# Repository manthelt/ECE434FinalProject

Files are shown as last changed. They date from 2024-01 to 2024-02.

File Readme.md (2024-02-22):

# ECE434 Sound Project
 Larissa Krakora, Ash Collins, Logan Manthey

<!-- markdown-toc start - Don't edit this section. Run M-x markdown-toc-refresh-toc -->
**Table of Contents**

- [ECE434 Sound Project](#ece434-sound-project)
    - [Executive Summary](#executive-summary)
    - [Packaging](#packaging)
    - [Installation Instructions](#installation-instructions)
    - [User Instructions](#user-instructions)
    - [Highlights](#highlights)
        - [Video](#video)
    - [Theory of Operation](#theory-of-operation)
        - [Hardware](#hardware)
            - [BOM](#bom)
            - [Keyboard Section](#keyboard-section)
                - [Schematic and PCB](#schematic-and-pcb)
                - [Resistor List for Note Values](#resistor-list-for-note-values)
            - [Pot Section](#pot-section)
        - [Software](#software)
            - [Reading in the values](#reading-in-the-values)
            - [Creating Sound](#creating-sound)
            - [Storing Recorded Sound](#storing-recorded-sound)
            - [Changing Octaves](#changing-octaves)
            - [Switching Songs](#switching-songs)
    - [Work Breakdown](#work-breakdown)
    - [Future Work](#future-work)
    - [Conclusions](#conclusions)

<!-- markdown-toc end -->

## Executive Summary

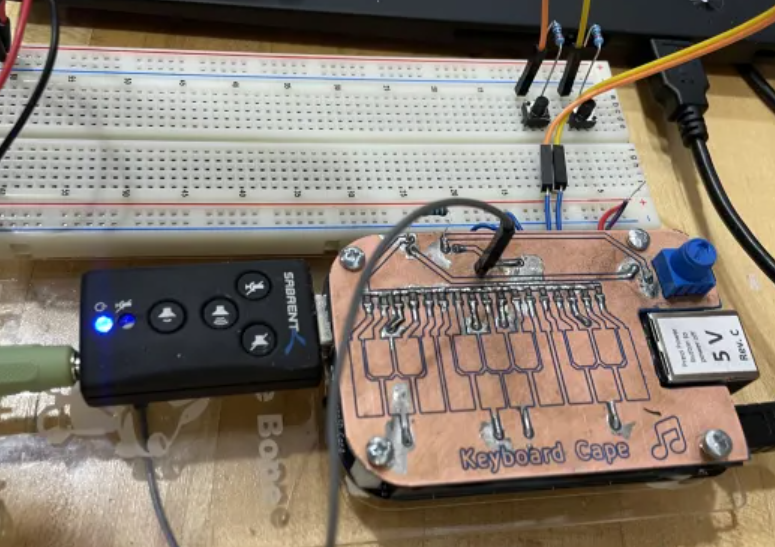
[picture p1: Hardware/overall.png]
|  | 
|:--:| 
| *Project Overview* |

This project is centered around making a digital synth using a custom designed keyboard cape. The inspiration for this project came from the Stylophone, an analog synth which used a stylus keyboard. Our project currently has capability to play songs, navigate songs, take and play user input, record and play back user input, and has two octaves for that "manual mode". We also have a simple UI via Flask for the controls, and the display of the title of the current song. We wanted to add audio visualisation on an LCD, but we were barely even able to get anything to display on the LCD. We gave that up as we sunk too many hours into it and would rather add new features. Our project has many different capabilities related to sound.

## Packaging
- Most of our product is standard wires, pots, switch buttons, etc. except for our custom "Keyboard Cape"
- Our cape acts as a voltage divider, allowing us to read in analog values of voltage to differentiate between notes

Hackster IO Link: https://www.hackster.io/larissa3/sound-project-77327a

ELinux Page Link: https://elinux.org/ECE434_Project_-_Sound_Project

## Installation Instructions
- Read-only GitHub: https://github.com/manthelt/ECE434FinalProject

1. Clone the repo
2. Run sudo ./install.sh
3. Run sudo ./setup.sh
4. Move .asoundrc to your home directory
5. Use aplay -l to find out which card your USB Audio device is setup as
6. Change 
    pcm "hw:0,0" -> pcm "hw:[card #],0" 
    and
    card 0 -> card [card #]
    in ~/.asoundrc

- Custom PCB schematic in 'Schematic and PCB'
- USB Surround Sound Adapter: https://sabrent.com/products/usb-sbcv

## User Instructions
1. Run ./recordServerNew.py
2. Visit https://localhost:8081

## Highlights
- Play a variety of songs
- Backward, pause/play, and skip functionalities
- "Manual mode" that allows the user to play their own sequence of notes
- Record a sequence of notes and play them back

### Video
Here is a video that shows our project in operation.

[Sound Project Demo Video](https://youtu.be/Gq4ZqvmgP8Y?si=p0Maj8yswmgwlebh)

## Theory of Operation
- Input from buttons > navigate through songs > display via Flask
- Input from cape while in manual mode > play various notes
- Manual mode is navigated to the same way other songs are > input only taken in during manual mode > other songs do not play during manual mode

### Hardware
This section decribes the hardware portion of the project and which parts and designs were used.

#### BOM
    - 17 1206 Resistor of Varying Sizes
      -  [Resistor List for Note Values](#resistor-list-for-note-values)
    - 1 Potenimeter
    - 2 2 Pin Male Connectors
    - 1 1 Pin Male Connector 
*Note for the connectors I used large ones that I cut down to size*

#### Keyboard Section
This section decribes the keyboard section of the hardware and it's theory of operation 

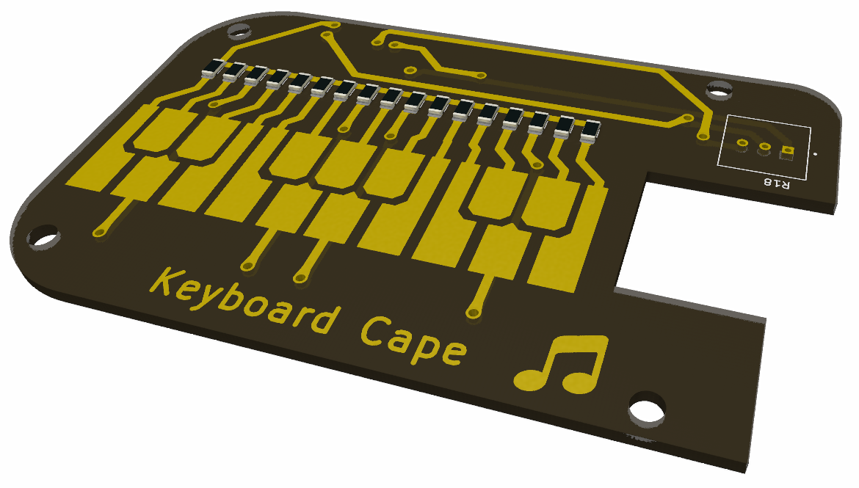
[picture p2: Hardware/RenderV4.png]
|  | 
|:--:| 
| *Beagle Bone Keyboard Cape Render* |

In short this keyboard acts as a form of potentiometer where connecting the 1.8 volt line to the different nets allows a different value to be read by the analog input as there is a different resistor connected to each one of the note nets.

##### Schematic and PCB
The keyboard cape was designed using KiCAD EDA software. KiCAD is an open source easy to use EDA software that allowed us to quickly design and then print out a PCB prototype on campus using the CNC mill. If we were going to redesign this for real manufacture we would add more headers to make it more stable. We would also add a spot for a pull down resistor to the board itself.

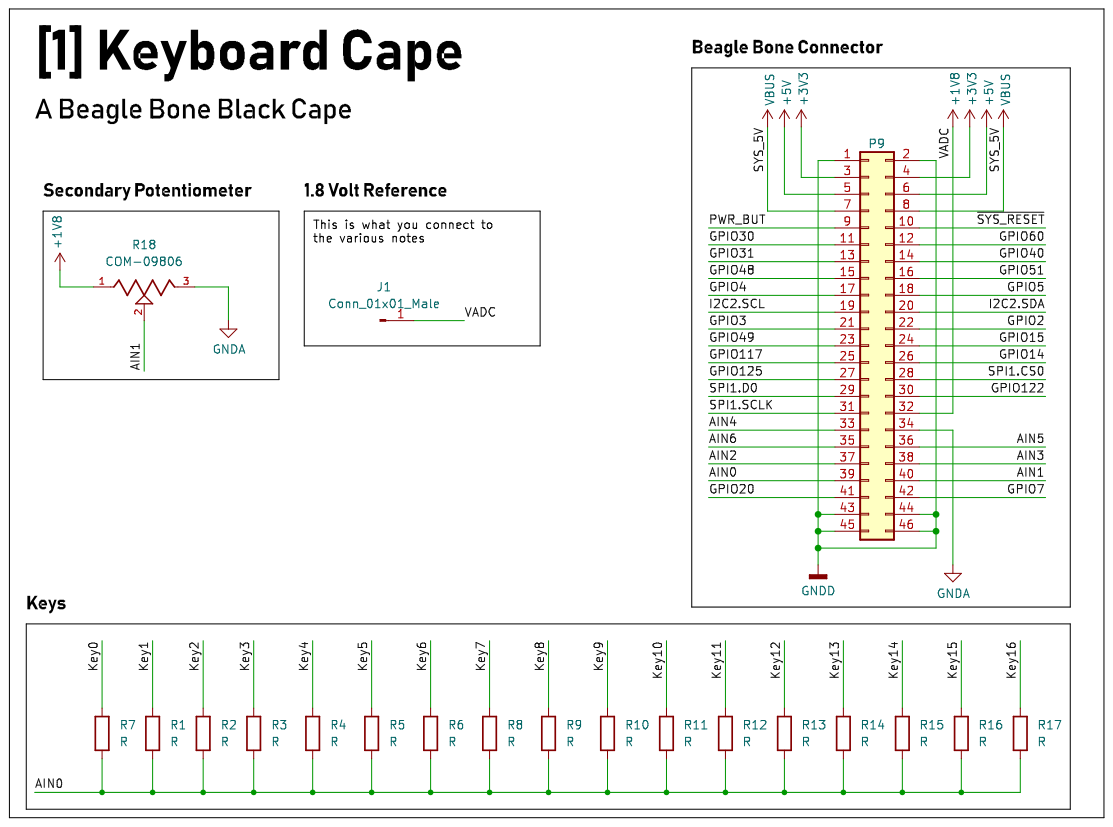
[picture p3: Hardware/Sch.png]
|  | 
|:--:| 
| *Beagle Bone Keyboard Cape Schematic View* |

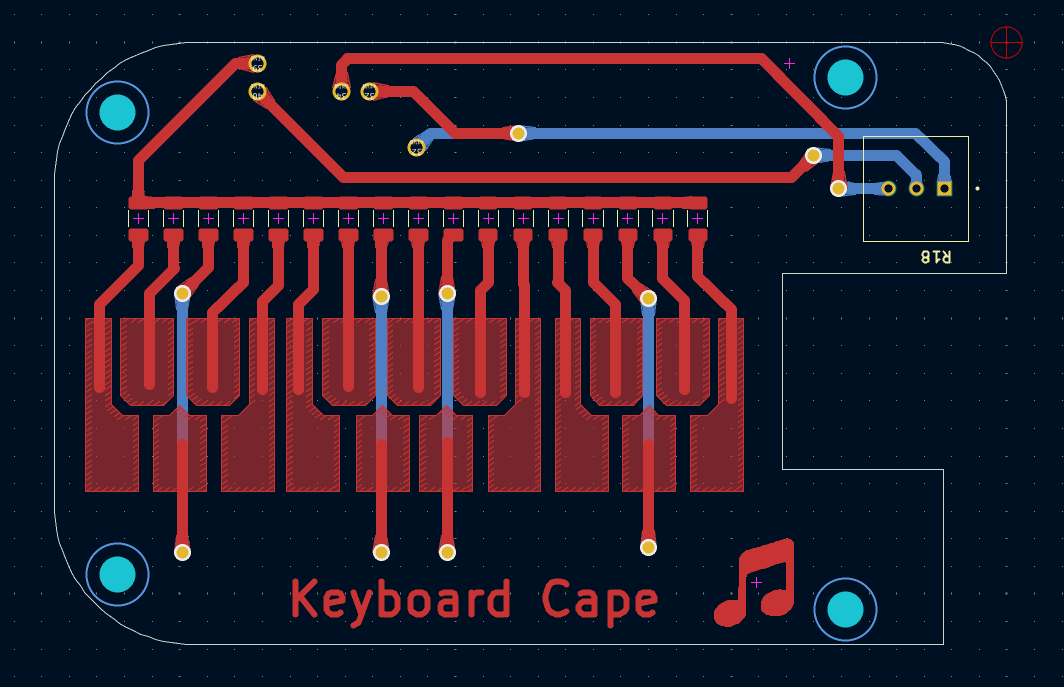
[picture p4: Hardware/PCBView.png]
|  | 
|:--:| 
| *Beagle Bone Keyboard Cape PCB View* |

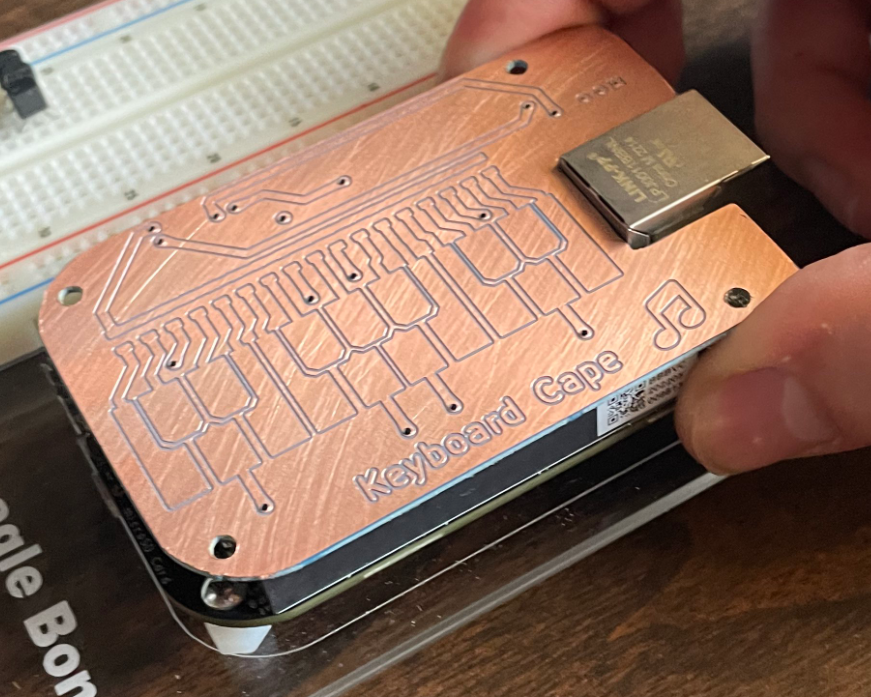
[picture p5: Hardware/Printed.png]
|  | 
|:--:| 
| *Beagle Bone Keyboard Cape Inital CNC Print* |

##### Resistor List for Note Values
These values were chosen to allow for a somewhat even distrubtion of values which will translate to a even distrubtion of values. We then added a pull down resistor to allow for a even larger distributing of notes. 

```
Note  Ohm
0     47000
1     33000
2     22000
3     15000
4     10000
5     6800
6     4700
7     3300
8     2200
9     1500
10    1000
11    680
12    470
13    330
14    220
15    150
16    100
17    0
```

#### Pot Section
In addition to the keyboard acting as a potentiometer there is also a normal potentiometer that can act as a volume control or however you would like to program it. That potentiometer is located here.

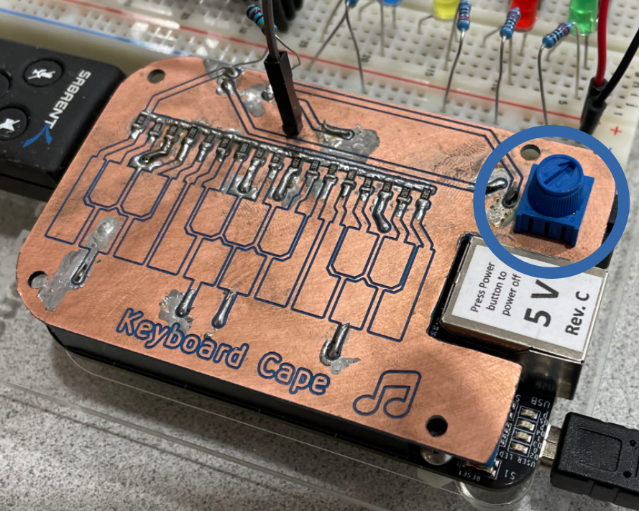
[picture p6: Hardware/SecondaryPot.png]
|  | 
|:--:| 
| *Beagle Bone Keyboard Cape Inital Print* |

### Software

#### Reading in the values
- Analog input via /sys/bus/iio
- Button input via gpio

#### Creating Sound
- While in manual mode, user hits the keys with connected wire
- Software reads in analog voltage input via /sys/bus/iio
- That analog voltage value corresponds to a frequency that is then played

#### Storing Recorded Sound
- User hits keys
- Notes are read in via /sys/bus/iio
- Durations are determined based on the time the user started playing the note and when they stopped

#### Changing Octaves
- Take in input from potentiometer
- Use that value as a boolean to determine offset for array index of frequencies

#### Switching Songs
- Buttons on Flask navigate to new page to control navigation through songs

## Work Breakdown

- PCB Design and Solder
  Logan

- Sound Generation and USB Audio
  Logan, Ash, Larissa

- LCD Visualization (not working - dropped)
  Ash, Larissa

- Flask
  Ash, Larissa

- Documentation
  Logan, Ash, Larissa

## Future Work
Future Additions
       - More features on the Flask App
       - More Synth Options and possbile Digital Signal Processing
         - Possible Second Pot Features
           - Pitch Bend
           - Wave Adjustment (Example: Sin Wave to Sawtooth to Square)
        - Being able to play over background songs and beats
          - This would let you solo with the keyboard over tunes like free bird
        - Adding a loop for recording playback would be able to allow for more intense soloing
        - LCD Screen
          - We attempted to get the LCD screen to work with the bone but this proved to be very
            difficult especially with a UI if we had LCD working with it we could make it into a
            smaller self contained package
        - Hardware
          - Adding buttons to the cape
          - Making the cape more stable on the bone
          - Printing the PCB at a PCB House

## Conclusions

Overall our group thinks our project was a success. Our approach of making something simple and
adding features to it proved to be very useful and allowed us to pivot as needed. This also
allowed us to always have something to demo at every stage of our project. We also thought
the interactive nature of the project made this a really fun project to demo.

Above in future work shows a few different features that we would like to add to the project.

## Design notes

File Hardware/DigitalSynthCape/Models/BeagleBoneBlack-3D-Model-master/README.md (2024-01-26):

BeagleBone Black 3D Model
=========================
 
SolidWorks 3D model of the BeagleBone Black

Contains the following:
- SolidWorks, IGES, STEP, STL files
- 3D PDF (open in Adobe Reader)

### To download, click "Download ZIP" to the right   ==>

Made available by Logic Supply based on information from BeagleBoard.org

Visit Logic Supply to buy the BeagleBone Black and accessories at http://www.logicsupply.com/products/bb_bblk_000

Follow us on Google+ for updates and more information: https://plus.google.com/u/0/b/103613886667848850929/

Designed by Rodney Hill and Hans Brakeley for Logic Supply.

Creative Commons Attribution 3.0 Unported License. To view a copy of this license,
visit http://creativecommons.org/licenses/by/3.0/. All text above must be included in any redistribution.

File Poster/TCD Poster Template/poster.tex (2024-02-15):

% unofficial poster template for Trinity College Dublin
% which is a fork of the unofficial University of Texas at Arlington Math Poster template:
% which is a fork of the unofficial University of Lethbridge Poster template: https://www.overleaf.com/latex/templates/university-of-lethbridge-unofficial-poster-template/nddfzgvqvfwf
% which is a fork of unofficial University of Alberta Poster template: 
% which is a fork of Yale template: https://www.overleaf.com/latex/templates/yale-poster-template/rjpgqfgvsjcv
% which is a fork of the UMich template https://www.overleaf.com/latex/templates/university-of-michigan-umich-poster-template/xpnqzzxwbjzc
% which is fork of the MSU template https://www.overleaf.com/latex/templates/an-unofficial-poster-template-for-michigan-state-university/wnymbgpxnnwd
% which is a fork of https://www.overleaf.com/latex/templates/an-unofficial-poster-template-for-new-york-university/krgqtqmzdqhg
% which is a fork of https://github.com/anishathalye/gemini
% also refer to https://github.com/k4rtik/uchicago-poster

\documentclass[final]{beamer}

% ====================
% Packages
% ====================

\usepackage[T1]{fontenc}
\usepackage[utf8]{luainputenc}
\usepackage{lmodern}
\usepackage[size=custom, width=122,height=91, scale=1.2]{beamerposter}
\usetheme{gemini}
\usecolortheme{msu}
\usepackage{graphicx}
\usepackage{booktabs}
\usepackage{tikz}
\usepackage{pgfplots}
\pgfplotsset{compat=1.14}
\usepackage{anyfontsize}

% ====================
% Lengths
% ====================

% If you have N columns, choose \sepwidth and \colwidth such that
% (N+1)*\sepwidth + N*\colwidth = \paperwidth
\newlength{\sepwidth}
\newlength{\colwidth}
\setlength{\sepwidth}{0.025\paperwidth}
\setlength{\colwidth}{0.3\paperwidth}

\newcommand{\separatorcolumn}{\begin{column}{\sepwidth}\end{column}}

% ====================
% Title
% ====================

\title{Some fancy title: followed by some more text}

\author{Your Name}
% add following line if you have co-author(s)
% Coauthor One$^{2}$, Coauthor Two$^{3}$

\institute[shortinst]{\textbf{Trinity College Dublin}, The University of Dublin}

% ====================
% Footer (optional)
% ====================

\footercontent{Mathposium \hfill
  \href{mailto:youremail@tcd.ie}{youremail@tcd.ie}}
% (can be left out to remove footer)

% ====================
% Logo
% ====================

% use this to include logos on the left and/or right side of the header:
% Left: institution
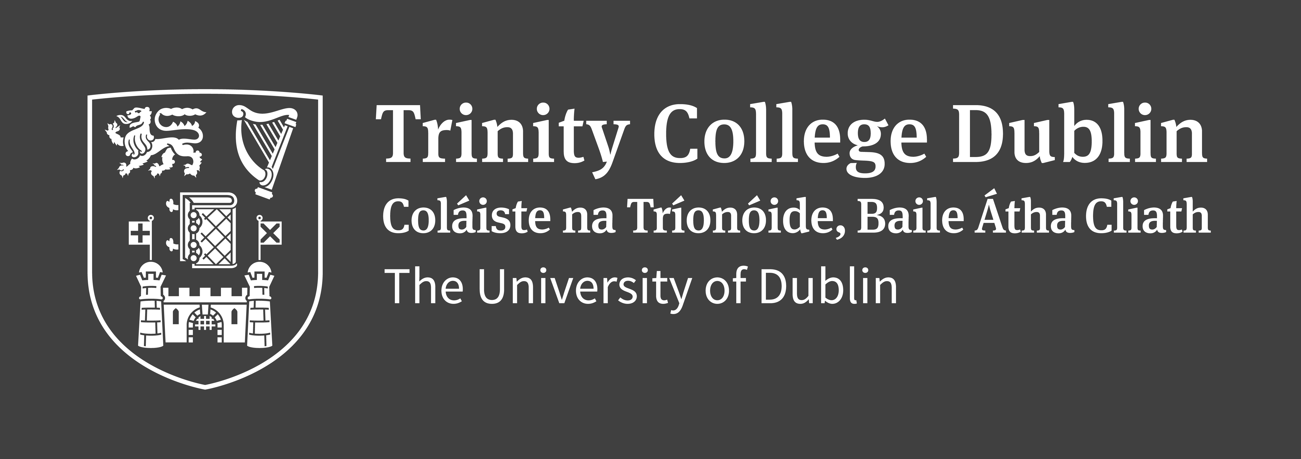
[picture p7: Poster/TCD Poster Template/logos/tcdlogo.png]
 \logoright{}
% Right: funding agencies and other affilations 
%\logoright{\includegraphics[height=7cm]{logos/NSF.eps}}

% ====================
% Body
% ====================

\begin{document}

\begin{frame}[t]
\begin{columns}[t]
\separatorcolumn

\begin{column}{\colwidth}

  \begin{block}{A block title}

    Some block contents, followed by a diagram, followed by a dummy paragraph.

    \begin{figure}
      \centering
                    
    \end{figure}

    Lorem ipsum dolor sit amet, consectetur adipiscing elit. Morbi ultricies
    eget libero ac ullamcorper. Integer et euismod ante. Aenean vestibulum
    lobortis augue, ut lobortis turpis rhoncus sed. Proin feugiat nibh a
    lacinia dignissim. Proin scelerisque, risus eget tempor fermentum, ex
    turpis condimentum urna, quis malesuada sapien arcu eu purus.

  \end{block}

  \begin{block}{A block containing a list}

    Nam vulputate nunc felis, non condimentum lacus porta ultrices. Nullam sed
    sagittis metus. Etiam consectetur gravida urna quis suscipit.

    \begin{itemize}
      \item \textbf{Mauris tempor} risus nulla, sed ornare
      \item \textbf{Libero tincidunt} a duis congue vitae
      \item \textbf{Dui ac pretium} morbi justo neque, ullamcorper
    \end{itemize}

    Eget augue porta, bibendum venenatis tortor.

  \end{block}

  \begin{alertblock}{A highlighted block}

    This block catches your eye, so \textbf{important stuff} should probably go
    here.

    Curabitur eu libero vehicula, cursus est fringilla, luctus est. Morbi
    consectetur mauris quam, at finibus elit auctor ac. Aliquam erat volutpat.
    Aenean at nisl ut ex ullamcorper eleifend et eu augue. Aenean quis velit
    tristique odio convallis ultrices a ac odio.

    \begin{itemize}
      \item \textbf{Fusce dapibus tellus} vel tellus semper finibus. In
        consequat, nibh sed mattis luctus, augue diam fermentum lectus.
      \item \textbf{In euismod erat metus} non ex. Vestibulum luctus augue in
        mi condimentum, at sollicitudin lorem viverra.
      \item \textbf{Suspendisse vulputate} mauris vel placerat consectetur.
        Mauris semper, purus ac hendrerit molestie, elit mi dignissim odio, in
        suscipit felis sapien vel ex.
    \end{itemize}

    Aenean tincidunt risus eros, at gravida lorem sagittis vel. Vestibulum ante
    ipsum primis in faucibus orci luctus et ultrices posuere cubilia Curae.

  \end{alertblock}

\end{column}

\separatorcolumn

\begin{column}{\colwidth}

  \begin{block}{A block containing an enumerated list}

    Vivamus congue volutpat elit non semper. Praesent molestie nec erat ac
    interdum. In quis suscipit erat. \textbf{Phasellus mauris felis, molestie
    ac pharetra quis}, tempus nec ante. Donec finibus ante vel purus mollis
    fermentum. Sed felis mi, pharetra eget nibh a, feugiat eleifend dolor. Nam
    mollis condimentum purus quis sodales. Nullam eu felis eu nulla eleifend
    bibendum nec eu lorem. Vivamus felis velit, volutpat ut facilisis ac,
    commodo in metus.

    \begin{enumerate}
      \item \textbf{Morbi mauris purus}, egestas at vehicula et, convallis
        accumsan orci. Orci varius natoque penatibus et magnis dis parturient
        montes, nascetur ridiculus mus.
      \item \textbf{Cras vehicula blandit urna ut maximus}. Aliquam blandit nec
        massa ac sollicitudin. Curabitur cursus, metus nec imperdiet bibendum,
        velit lectus faucibus dolor, quis gravida metus mauris gravida turpis.
      \item \textbf{Vestibulum et massa diam}. Phasellus fermentum augue non
        nulla accumsan, non rhoncus lectus condimentum.
    \end{enumerate}

  \end{block}

  \begin{block}{Fusce aliquam magna velit}

    Et rutrum ex euismod vel. Pellentesque ultricies, velit in fermentum
    vestibulum, lectus nisi pretium nibh, sit amet aliquam lectus augue vel
    velit. Suspendisse rhoncus massa porttitor augue feugiat molestie. Sed
    molestie ut orci nec malesuada. Sed ultricies feugiat est fringilla
    posuere.

    \begin{figure}
      \centering
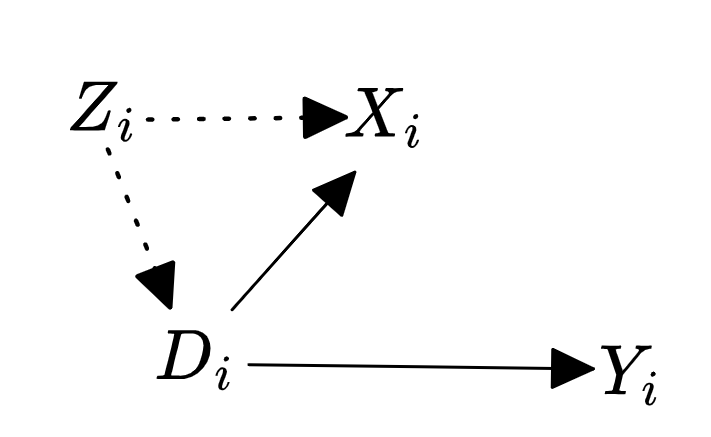
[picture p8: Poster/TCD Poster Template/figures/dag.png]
        

      \caption{Another figure caption.}
    \end{figure}

  \end{block}

  \begin{block}{Nam cursus consequat egestas}

    Nulla eget sem quam. Ut aliquam volutpat nisi vestibulum convallis. Nunc a
    lectus et eros facilisis hendrerit eu non urna. Interdum et malesuada fames
    ac ante \textit{ipsum primis} in faucibus. Etiam sit amet velit eget sem
    euismod tristique. Praesent enim erat, porta vel mattis sed, pharetra sed
    ipsum. Morbi commodo condimentum massa, \textit{tempus venenatis} massa
    hendrerit quis. Maecenas sed porta est. Praesent mollis interdum lectus,
    sit amet sollicitudin risus tincidunt non.

    Etiam sit amet tempus lorem, aliquet condimentum velit. Donec et nibh
    consequat, sagittis ex eget, dictum orci. Etiam quis semper ante. Ut eu
    mauris purus. Proin nec consectetur ligula. Mauris pretium molestie
    ullamcorper. Integer nisi neque, aliquet et odio non, sagittis porta justo.

    \begin{itemize}
      \item \textbf{Sed consequat} id ante vel efficitur. Praesent congue massa
        sed est scelerisque, elementum mollis augue iaculis.
        \begin{itemize}
          \item In sed est finibus, vulputate
            nunc gravida, pulvinar lorem. In maximus nunc dolor, sed auctor eros
            porttitor quis.
          \item Fusce ornare dignissim nisi. Nam sit amet risus vel lacus
            tempor tincidunt eu a arcu.
          \item Donec rhoncus vestibulum erat, quis aliquam leo
            gravida egestas.
        \end{itemize}
      \item \textbf{Sed luctus, elit sit amet} dictum maximus, diam dolor
        faucibus purus, sed lobortis justo erat id turpis.
      \item \textbf{Pellentesque facilisis dolor in leo} bibendum congue.
        Maecenas congue finibus justo, vitae eleifend urna facilisis at.
    \end{itemize}

  \end{block}

\end{column}

\separatorcolumn

\begin{column}{\colwidth}

  \begin{exampleblock}{A highlighted block containing some math}

    A different kind of highlighted block.

    $$
    \int_{-\infty}^{\infty} e^{-x^2}\,dx = \sqrt{\pi}
    $$

    Interdum et malesuada fames $\{1, 4, 9, \ldots\}$ ac ante ipsum primis in
    faucibus. Cras eleifend dolor eu nulla suscipit suscipit. Sed lobortis non
    felis id vulputate.

    \heading{A heading inside a block}

    Praesent consectetur mi $x^2 + y^2$ metus, nec vestibulum justo viverra
    nec. Proin eget nulla pretium, egestas magna aliquam, mollis neque. Vivamus
    dictum $\mathbf{u}^\intercal\mathbf{v}$ sagittis odio, vel porta erat
    congue sed. Maecenas ut dolor quis arcu auctor porttitor.

    \heading{Another heading inside a block}

    Sed augue erat, scelerisque a purus ultricies, placerat porttitor neque.
    Donec $P(y \mid x)$ fermentum consectetur $\nabla_x P(y \mid x)$ sapien
    sagittis egestas. Duis eget leo euismod nunc viverra imperdiet nec id
    justo.

  \end{exampleblock}

  \begin{block}{Nullam vel erat at velit convallis laoreet}

    Class aptent taciti sociosqu ad litora torquent per conubia nostra, per
    inceptos himenaeos. Phasellus libero enim, gravida sed erat sit amet,
    scelerisque congue diam. Fusce dapibus dui ut augue pulvinar iaculis.

    \begin{table}
      \centering
      \begin{tabular}{l r r c}
        \toprule
        \textbf{First column} & \textbf{Second column} & \textbf{Third column} & \textbf{Fourth} \\
        \midrule
        Foo & 13.37 & 384,394 & $\alpha$ \\
        Bar & 2.17 & 1,392 & $\beta$ \\
        Baz & 3.14 & 83,742 & $\delta$ \\
        Qux & 7.59 & 974 & $\gamma$ \\
        \bottomrule
      \end{tabular}
      \caption{A table caption.}
    \end{table}

    Donec quis posuere ligula. Nunc feugiat elit a mi malesuada consequat. Sed
    imperdiet augue ac nibh aliquet tristique. Aenean eu tortor vulputate,
    eleifend lorem in, dictum urna. Proin auctor ante in augue tincidunt
    tempor. Proin pellentesque vulputate odio, ac gravida nulla posuere
    efficitur. Aenean at velit vel dolor blandit molestie. Mauris laoreet
    commodo quam, non luctus nibh ullamcorper in. Class aptent taciti sociosqu
    ad litora torquent per conubia nostra, per inceptos himenaeos.

  \end{block}

  \begin{block}{References}

    \nocite{*}
    \footnotesize{\bibliographystyle{plain}\bibliography{poster}}

  \end{block}

\end{column}

\separatorcolumn
\end{columns}
\end{frame}

\end{document}

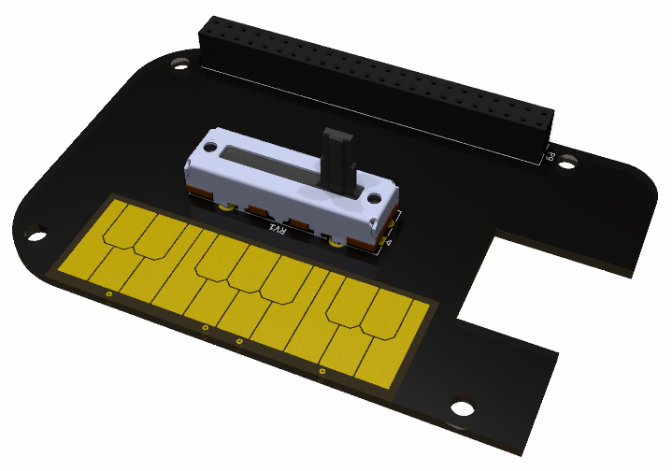
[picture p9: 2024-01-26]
Hardware/RenderV1.png

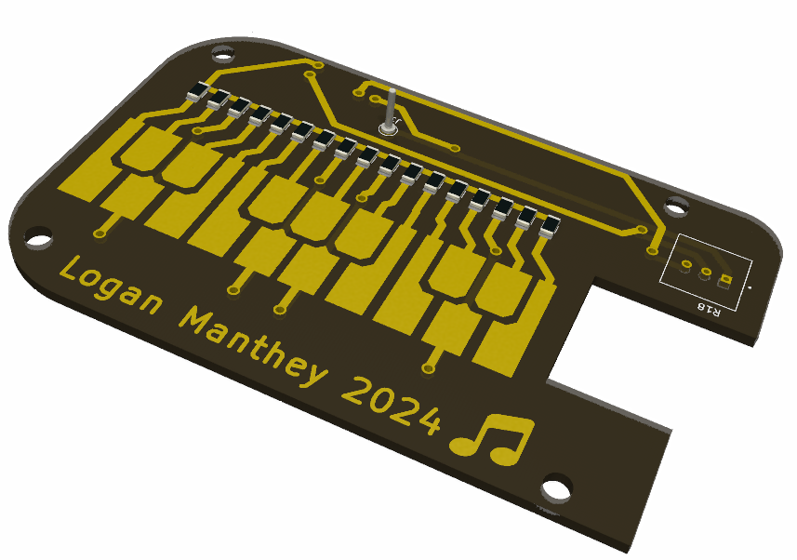
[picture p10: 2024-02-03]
Hardware/RenderV3.png

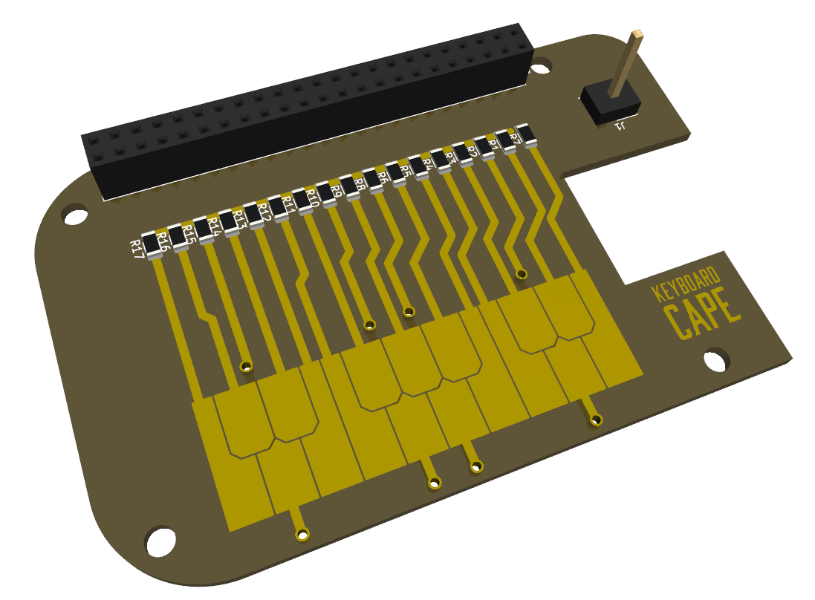
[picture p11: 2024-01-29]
Hardware/RenderV2.png

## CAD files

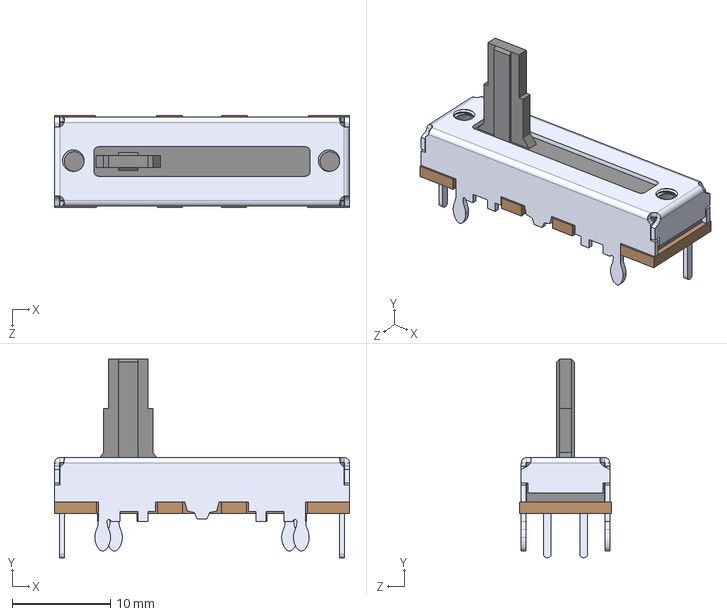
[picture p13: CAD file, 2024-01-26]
Hardware/DigitalSynthCape/Models/PTA1543-2010CIB103.step
30.0 x 20.2 x 9.40 mm

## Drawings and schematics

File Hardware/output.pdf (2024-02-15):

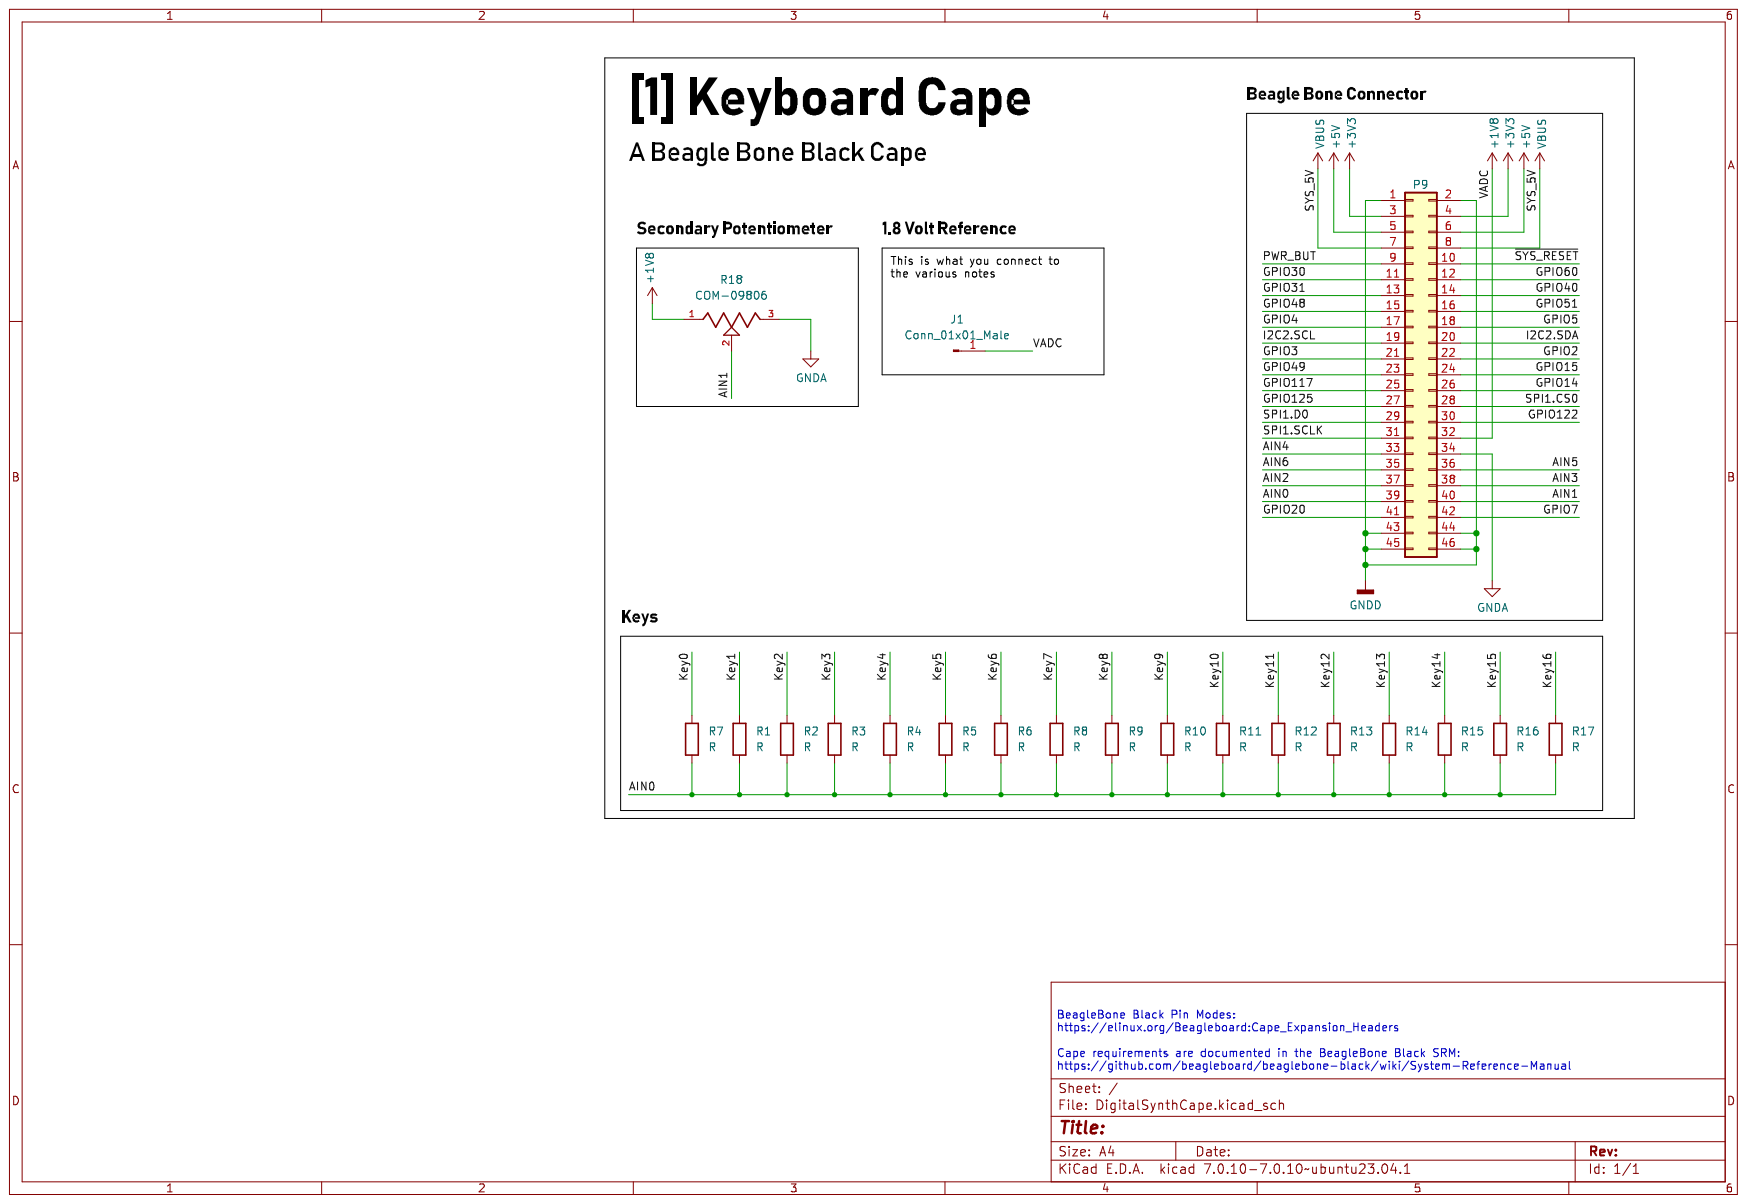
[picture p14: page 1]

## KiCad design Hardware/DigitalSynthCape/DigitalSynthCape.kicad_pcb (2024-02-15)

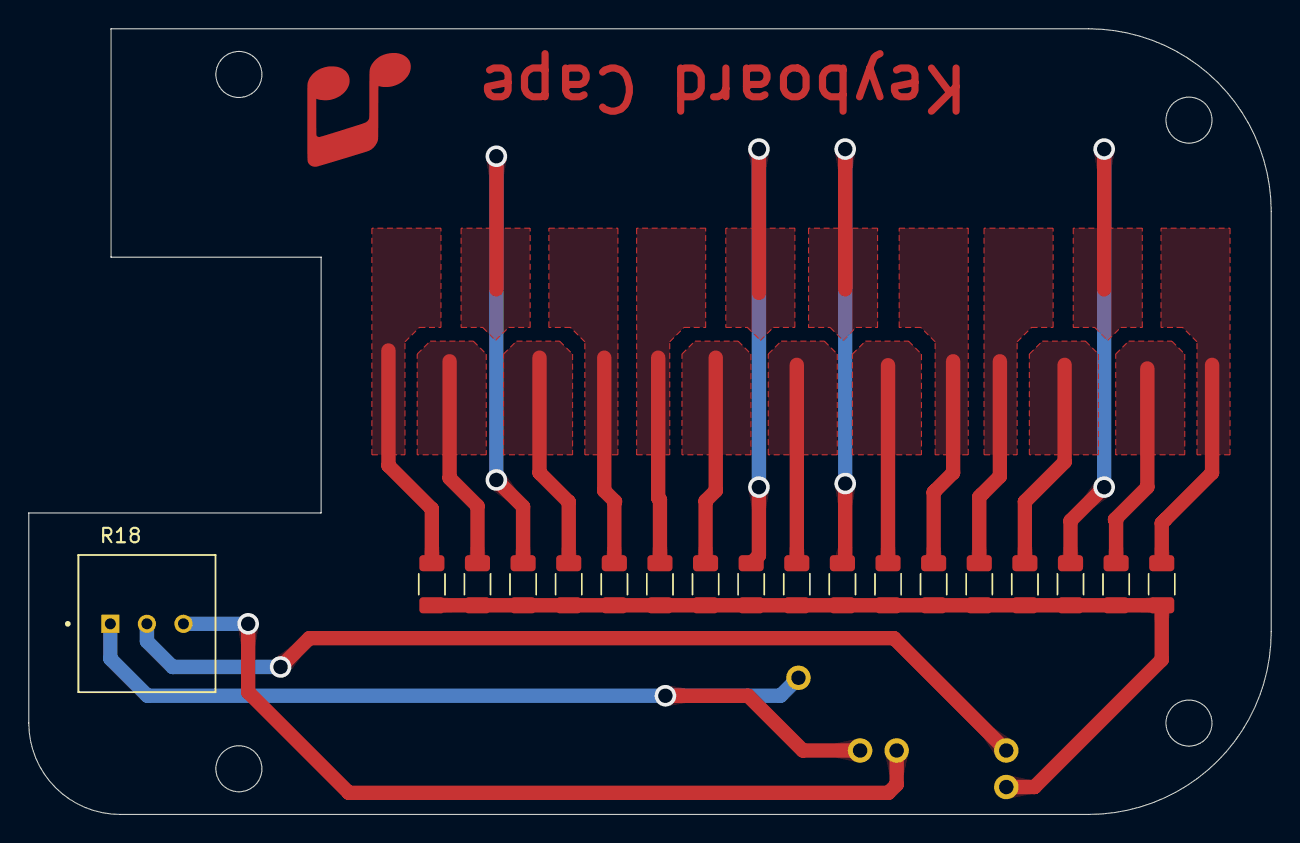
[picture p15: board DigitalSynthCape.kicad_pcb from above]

Board: 2 copper layers, 86.4 x 54.6 mm, 23 parts (0 on the bottom side), 4 nets.

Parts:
MH1, MH2, MH3, MH4: MountingHole_3.2mm_M3_DIN965
P9: BeagleBone_Black_Header; PinHeader_2x23_P2.54mm_Vertical
R1, R2, R3, R4, R5, R6, R7, R8, R9, R10, R11, R12, R13, R14, R15, R16, R17: R; R_1206_3216Metric
R18: COM-09806; TRIM_COM-09806

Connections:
+1V8: P9.32, R18.1
/AIN0: P9.39, R1.2, R2.2, R3.2, R4.2, R5.2, R6.2, R7.2, R8.2, R9.2, R10.2, R11.2, R12.2, R13.2, R14.2, R15.2, R16.2, R17.2
/AIN1: P9.40, R18.2
GNDA: P9.34, R18.3

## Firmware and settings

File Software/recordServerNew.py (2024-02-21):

#!/usr/bin/env python3
# server.py
# Author: Ash Collins
# Edited: 2/20/2024
# import smbus
from flask import Flask, render_template, flash
import numpy as np
import simpleaudio as sa
import time
import gpiod

#frequency = 440  # Our played note will be 440 Hz
fs = 44100  # 44100 samples per second
seconds = 20  # Note duration of 3 seconds
numNotes = 17

C3 = 130.81
CS3 = 138.59
D3 = 146.83
DS3 = 155.56
E3 = 164.81
F3 = 174.61
FS3 = 185
G3 = 196
GS3 = 207.65
A3 = 220
AS3 = 233.08
B3 = 246.94

C4 = 261.63
CS4 = 277.18
D4 = 293.66
DS4 = 311.13
E4 = 329.63
F4 = 349.23
FS4 = 369.99
G4 = 392
GS4 = 415.3
A4 = 440
AS4 = 466.16
B4 = 493.88
C5 = 523.25
CS5 = 554.37
D5 = 587.33
DS5 = 622.25
E5 = 659.25

frequencies = [C3, CS3, D3, DS3, E3, F3, FS3, G3, GS3, A3, AS3, B3, C4, CS4, D4, DS4, E4 ,C4, CS4, D4, DS4, E4, F4, FS4, G4, GS4, A4, AS4, B4, C5, CS5, D5, DS5, E5]
ranges = [4000, 3900, 3800, 3700, 3500, 3350, 3000, 2800, 2500, 2100, 1700, 1300, 1200, 750, 550, 400, 50]
inputF = open('/sys/bus/iio/devices/iio:device0/in_voltage0_raw', "r")
inputF2 = open('/sys/bus/iio/devices/iio:device0/in_voltage1_raw', "r")
frequency = 0
audios = np.ones(dtype=np.int16, shape=(numNotes*2, seconds * fs))
CONSUMER = 'sounds'
switchChip = gpiod.Chip('0')
getLines = switchChip.get_lines([30, 31])
ledLines = switchChip.get_lines([5, 13])
getLines.request(consumer=CONSUMER, type=gpiod.LINE_REQ_DIR_IN)
ledLines.request(consumer=CONSUMER, type=gpiod.LINE_REQ_DIR_OUT)
NUM_SONGS = 3
songs = [sa.WaveObject.from_wave_file('Rickroll.wav'), sa.WaveObject.from_wave_file('LateAtNight.wav'), sa.WaveObject.from_wave_file('BlueHair.wav')]
names = ["Never Gonna Give You Up", "Late Night", "Blue Hair"]
curSong = 1
songPlaying = 0
manualInput = False
NUM_RECORD = 200
recording = np.zeros(NUM_RECORD)
rec_times = np.zeros(NUM_RECORD)
record_in = 0

def getIndex(val):
    for i in range(numNotes):
        if val >= ranges[i]:
            return i
    return -1

for i in range(numNotes*2):
    frequency = frequencies[i]
    # Generate array with seconds*sample_rate steps, ranging between 0 and seconds
    t_short = np.linspace(0, 1/frequency, int(fs/frequency), False)
    #t = np.linspace(0, seconds, seconds * fs, False)

    # Generate a [frequency] Hz sine wave
    note_short = np.sin(frequency*t_short*2*np.pi)
    # Ensure that highest value is in 16-bit range
    note_short = note_short * (2**14 - 1) / np.max(np.abs(note_short))
    note = np.resize(note_short, seconds * fs)
    
    # Convert to 16-bit data
    audios[i] = note.astype(np.int16)


aVal = int(inputF.read())
inputF.seek(0)
frequency = frequencies[getIndex(aVal)]

# Start playback
# play_obj2.stop()
time.sleep(0.3)
play_obj = sa.play_buffer(audios[0], 1, 2, fs)
play_obj.stop()

def playRecording():
    global play_obj
    if play_obj.is_playing():
        play_obj.stop()
        time.sleep(0.3)
    for i in range(record_in):
        if play_obj.is_playing():
            play_obj.stop()
            time.sleep(0.3)
        if recording[i] >= 0:
            play_obj = sa.play_buffer(audios[int(recording[i])], 1, 2, fs)
        time.sleep(rec_times[i])

    play_obj.stop()
    time.sleep(0.3)

app = Flask(__name__)
app.secret_key = "my_key"
@app.route("/")
def index():
    global names
    global curSong
    templateData = {
        'song'  : names[curSong],
        'play_str'  : "Start",
        'mode_str'  : "Manual"
    }
    return render_template('index.html', **templateData)

@app.route("/<flag>")
def action(flag):
    global curSong
    global play_obj
    global songs
    global names
    global songPlaying
    global manualInput
    global inputF
    global aVal
    global aVal2
    global frequency
    global frequencies
    global getLines
    global audios
    global record_in
    global recording
    if flag == "prev": 
        curSong = (curSong + NUM_SONGS - 1) % NUM_SONGS
        if play_obj.is_playing():
            play_obj.stop()
            time.sleep(0.3)
        play_obj = songs[curSong].play()
        songPlaying = True
        templateData = {
            'song'  : names[curSong],
            'play_str'  : "Stop",
            'mode_str'  : "Manual"
        }
        return render_template('index.html', **templateData)
    if flag == "next":
        curSong = (curSong + 1) % NUM_SONGS
        if play_obj.is_playing():
            play_obj.stop()
            time.sleep(0.3)
        play_obj = songs[curSong].play()
        songPlaying = True
        templateData = {
            'song'  : names[curSong],
            'play_str'  : "Stop",
            'mode_str'  : "Manual"
        }
        return render_template('index.html', **templateData)
    if flag == "play":
        if songPlaying:
            if play_obj.is_playing():
                play_obj.stop()
            songPlaying = False
            templateData = {
                'song'  : names[curSong],
                'play_str'  : "Start",
                'mode_str'  : "Manual"
            }
            return render_template('index.html', **templateData)
        else:
            if play_obj.is_playing():
                play_obj.stop()
                time.sleep(0.3)
            play_obj = songs[curSong].play()
            songPlaying = True
            templateData = {
                'song'  : names[curSong],
                'play_str'  : "Stop",
                'mode_str'  : "Manual"
            }
            return render_template('index.html', **templateData)
    if flag == "playback":
        playRecording()
    if flag == "mode":
        record = False
        ledLines.set_values([1,0])
        time_start = time.perf_counter()
        time_stop = time.perf_counter()
        prev_in = -1
        while True:
            if getLines.get_values()[0] == 1:
                templateData = {
                    'song'  : names[curSong],
                    'play_str'  : "Start",
                    'mode_str'  : "Manual"
                }
                return render_template('index.html', **templateData)
            if getLines.get_values()[1] == 1:
                record = not record
                if record:
                    recording = np.zeros(NUM_RECORD)
                    record_in = 0
                    time_start = time.perf_counter()
                    time_stop = time.perf_counter()
                    ledLines.set_values([1,1])
                else:
                    ledLines.set_values([0,0])
                    templateData = {
                        'song'  : names[curSong],
                        'play_str'  : "Start",
                        'mode_str'  : "Manual"
                    }
                    return render_template('index.html', **templateData)
                while getLines.get_values()[1] == 1:
                    pass
            inputF.seek(0)
            aVal = int(inputF.read())
            time.sleep(0.001)
            inputF.seek(0)
            aVal2 = int(inputF.read())
            inputF2.seek(0)
            offset = 0
            if int(inputF2.read()) >= 1:
                offset = 17
            if aVal != aVal2:
                continue
            index = getIndex(aVal)
            if index >= 0:
                index = index + offset
            if record and index != prev_in and record_in < NUM_RECORD:
                time_stop = time.perf_counter()
                rec_times[record_in] = time_stop - time_start
                recording[record_in] = prev_in
                record_in += 1
                time_start = time_stop
                prev_in = index
            if index < 0 or aVal <= 30:
                frequency = 0
                play_obj.stop()                    
            if index >= 0 and frequency != frequencies[index] and aVal > 30:
                frequency = frequencies[index]
                # Start playback
                play_obj.stop()
                time.sleep(0.35)
                play_obj = sa.play_buffer(audios[index], 1, 2, fs)
    ledLines.set_values([0,0])
    templateData = {
        'song'  : names[curSong],
        'play_str'  : "Start",
        'mode_str'  : "Manual"
    }
    return render_template('index.html', **templateData)

if __name__ == "__main__":
   app.run(host='0.0.0.0', port=8081, debug=True)

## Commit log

2023-09-20 Minor fixes and added setup file
    [recordServerNew.py]
2024-01-26 Started PCB
    [DigitalSynthCape.kicad_pcb, DigitalSynthCape.kicad_sch]
2024-01-26 Added Render
    [DigitalSynthCape.kicad_pcb, DigitalSynthCape.kicad_sch, PTA1543-2010CIB103.step]
2024-01-29 Updates to PCB
    [DigitalSynthCape.kicad_pcb]
2024-02-08 Added Gerbers
    [DigitalSynthCape.kicad_pcb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]
2024-02-15 Updates to Readme
    [DigitalSynthCape.kicad_sch]
2024-02-20 Progress on flask server (not working)
    [server.py]
2024-02-21 Recording with octave and buttons working
